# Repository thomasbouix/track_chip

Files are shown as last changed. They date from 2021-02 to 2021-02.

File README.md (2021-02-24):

# TrackChip, le traqueur autonome ! 
L'objectif de ce projet est double :
* Développer un traqueur autonome de précision ~10m (partie Device)
* Récupérer ces informations sur un client WEB (partie Cloud)

### Device
Le device en lui-même est basé sur un micro-controleur ESP32, entouré des périphériques suivant :
* Altimètre BMP180
* GPS ADA746
* Module Sigfox BRKWS01
* Batterie LIPO 1050mAh
* Régulateur de tension 5V Polulu U1V11F5

```
Les sources des bibliothèques des périphériques ainsi que du PCB sont disponibles dans le dossier /devices du git.
```
### Site Web
Le site internet possède les fonctionnalitées suivantes :
* Position de l'utilisateur
* Position du traqueur
* Calcul de la différence d'altitude
* Calcul du trajet en voiture pour rejoindre le traqueur
* Historique des positions du traqueur

```
Les sources du serveur, de la base de donnée et du site Web sont disponibles dans la partie cloud/ du git.
```

# Notice d'utilisation
Le système dans son ensemble possède le comportement suivant :
* Le device utilise le GPS quand il reçoit un signal
* Le device utilise le scrapping WiFi quand le GPS est indisponible
* La position est envoyée sur notre serveur via le réseau SigFox
* Les informations sont accessibles sur notre site via un client Web. 

### Device
Le device s'allume et s'éteint avec le boutton ON/OFF sur le côté de sa boîte protectrice.
Il envoie alors sa position toutes les 5 minutes.
```
Le programme faisant fonctionner le device peut-être modifié et téléversé avec l'IE Arduino.
Il faut simplement s'assurer que les librairies utilisées sont bien visibles en les ajoutant dans ~/Arduino/lib.
```

### Réseau SigFox
Le device envoie ses données sur un backend web en utilisant le réseau SigFox.
Ce backend redirigie ensuite ces informations sur notre serveur grâce à une fonction de callback.
On accède au backend via l'URL suivant :
```
https://backend.sigfox.com/auth/login
```

### Serveur
Le serveur est un ensemble de programmes gérant le site Web ainsi que la base de donnée. 
Il peut être hebergé sur une machine locale, ou bien sur internet via un VPS.
Afin d'avoir accès aux nombreux service de géolocalisation (carte, itinéraire, etc), nous avons utilisé différententes APIs fournies par Google.
Ces APIs nécéssitent une clef pour pouvoir y accéder qu'il faut générer en créant d'abord un compte Google Cloud Platform. 
Puis en copiant-collant cette clef à la place de la notre dans le fichier dev/cloud/php/map.php à la ligne 44 dans le lien du script.
En local, on peut lancer le site avec les commandes suivantes :
```
$ cd /path/to/sources
$ php -S 127.0.0.1.:8888
```

### Site Web
Nous avons choisi d'utiliser l'hébergeur always-data pour notre site.
Cela donnait un URL du type :
```
https://track-chip.alwaysdata.net/
```

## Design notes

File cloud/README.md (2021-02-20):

# Procédure à suivre pour se connecter au site

Ouvrir un navigateur internet (Chrome ou Chromium de préférence, ne fonctionne pas sur Safari) et taper l'adresse suivante : 
```
https://track-chip.alwaysdata.net/cloud/php/map.php
```

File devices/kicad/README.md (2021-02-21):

# KiCad - Architecture

## Librairie
```
Le fichier track_chip.lib contient tout les "symboles" créés pour le projet :
	- ESP32 NodeMCU
	- BMP180
	- ADA746
	- BRKWS01

La librairie contient aussi les symboles déjà présents par défaut dans KiCad, 
afin d'éliminer la dépendance à la version du logiciel.
```

## Schéma
```
Le fichier .sch représente le schéma du circuit électronique du système (Eeschema).
Il instancie les différents symboles de la librairie du projet.
```

## Empreintes

### Dimensions
```
- Largeur typique d'une piste : 1mm
- Largeur typique d'une alimentation : 2mm
- Ecart entre les pastilles : 2.54mm
- Diamètre typique de perçage : 0.8mm
- Diamètre typique de pastille : 1.5mm
```

### Plans de masse
```
Recommendations : faire des plans de masses.
Si il y a un domaine analogique et un domaine numérique, 
faire des plans de masse séparés et les relier avec une piste.
```

## Batterie
```
On utilise un circuit avec chargeur intégré.
```
# Version Sigfox
La version Sigfox utilise un module Wisol pour les communications.
C'est cette version qui a été retenue pour les démonstrations

# Version GSM
La version GSM utilise une carte SIM pour les communications.
Cette version est en cours de développement.

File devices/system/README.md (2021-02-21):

# Classe track_chip
Classe encapsulant les librairies pour les différents périphériques.
(Communication, capteurs, position etc ...)

# Précaution lors de l'upload du code 
Il faut débrancher le broche TX du GPS pour pouvoir téléverser le code depuis l'IDE arduino.
C'est parce que ce gps utilise le même port série que le calbe USB utilisé pour téléverser.

# Architecture du code 
* On utilise la liaison _Serial_ pour imprimer des caractères sur la liaison USB

* Le gps communique avec la liaison _Serial1_ sur les broches RX0 et TX0 de l'ESP32
	+ BAUDE=9600 par défaut

* Le wisol communique avec la liaison _Serial2_ sur les broches RX2 et TX2 de l'ESP32 
	+ BAUDE=9600 par défaut

# examples/class_system/
Ce dossier instancie un code example utilisant la classe track_chip
(En cours de développement)

# examples/bare_system/
Ce dossier instancie un code example utilisant les libairies sans la classe track_chip

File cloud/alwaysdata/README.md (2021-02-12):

# Procedure à suivre pour créer une cles SSH sur le serveur AlwaysData

## Etape 1 :

Générer la clé en local.
		
		$ mkdir -p $HOME/.ssh
		$ chmod 0700 $HOME/.ssh
		$ ssh-keygen -t ed25519 -f $HOME/.ssh/id_ed25519
		
		(tips : vous pouvez indiquez une passphrase vide pour pouvoir vous connecter directement sans la rentrer)

## Etape 2 :

Déclarer la clés publique (.pub) sur le serveur.

		$ ssh-copy-id -i $HOME/.ssh/id_ed25519.pub track-chip@ssh-track-chip.alwaysdata.net

## Etape 3 :

Se connecter au serveur en ssh.

		$ ssh track-chip@ssh-track-chip.alwaysdata.net

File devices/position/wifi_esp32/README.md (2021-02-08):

# Fonctions de localisation grâce aux réseaux Wifi
```
Ces fonctions ont été recopiées et intégrées à la classe TrackChip.
```

# Installation instructions using Arduino IDE Boards Manager
```
- Stable release link: `https://raw.githubusercontent.com/espressif/arduino-esp32/gh-pages/package_esp32_index.json`
- Development release link: `https://raw.githubusercontent.com/espressif/arduino-esp32/gh-pages/package_esp32_dev_index.json`

Starting with 1.6.4, Arduino allows installation of third-party platform packages using Boards Manager. We have packages available for Windows, Mac OS, and Linux (x86, amd64, armhf and arm64).

- Install the current upstream Arduino IDE at the 1.8 level or later. The current version is at the [Arduino website](http://www.arduino.cc/en/main/software).
- Start Arduino and open Preferences window.
- Enter one of the release links above into *Additional Board Manager URLs* field. You can add multiple URLs, separating them with commas.
- Open Boards Manager from Tools > Board menu and install *esp32* platform (and don't forget to select your ESP32 board from Tools > Board menu after installation).
```

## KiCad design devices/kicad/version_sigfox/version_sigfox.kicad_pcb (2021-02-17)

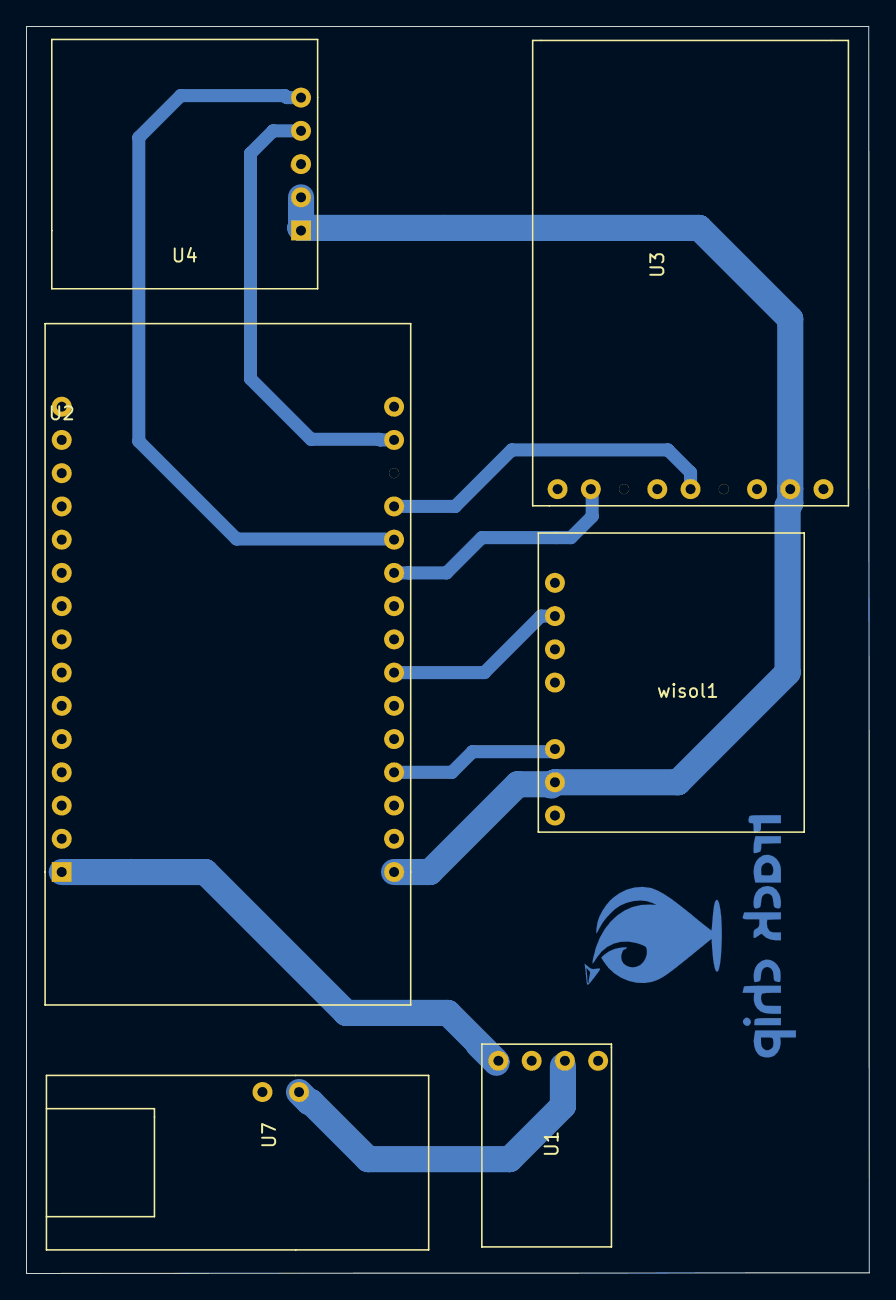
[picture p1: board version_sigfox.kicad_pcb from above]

Board: 2 copper layers, 64.4 x 95.3 mm, 6 parts (0 on the bottom side), 10 nets.

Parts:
U1: polulu
U2: esp32_NodeMCU-track_chip; esp32
U3: GPS_PA6H
U4: bmp180-track_chip; bmp180
U7: charger_mr010
wisol1: brkws01; BRWS01

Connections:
3V3: U2.16, U3.8, U4.1, U4.2, wisol1.6
5V: U1.4, U2.15
EN_GPS: U2.25, U3.2
GND: U1.3, U2.17, U3.7, U4.3, U7.2, wisol1.7
GPS_TX0: U2.27, U3.5
MCU_TX2: U2.22, wisol1.2
RST_WSL: U2.19, wisol1.5
SCL: U2.29, U4.4
SDA: U2.26, U4.5
VBAT: U1.2, U7.1

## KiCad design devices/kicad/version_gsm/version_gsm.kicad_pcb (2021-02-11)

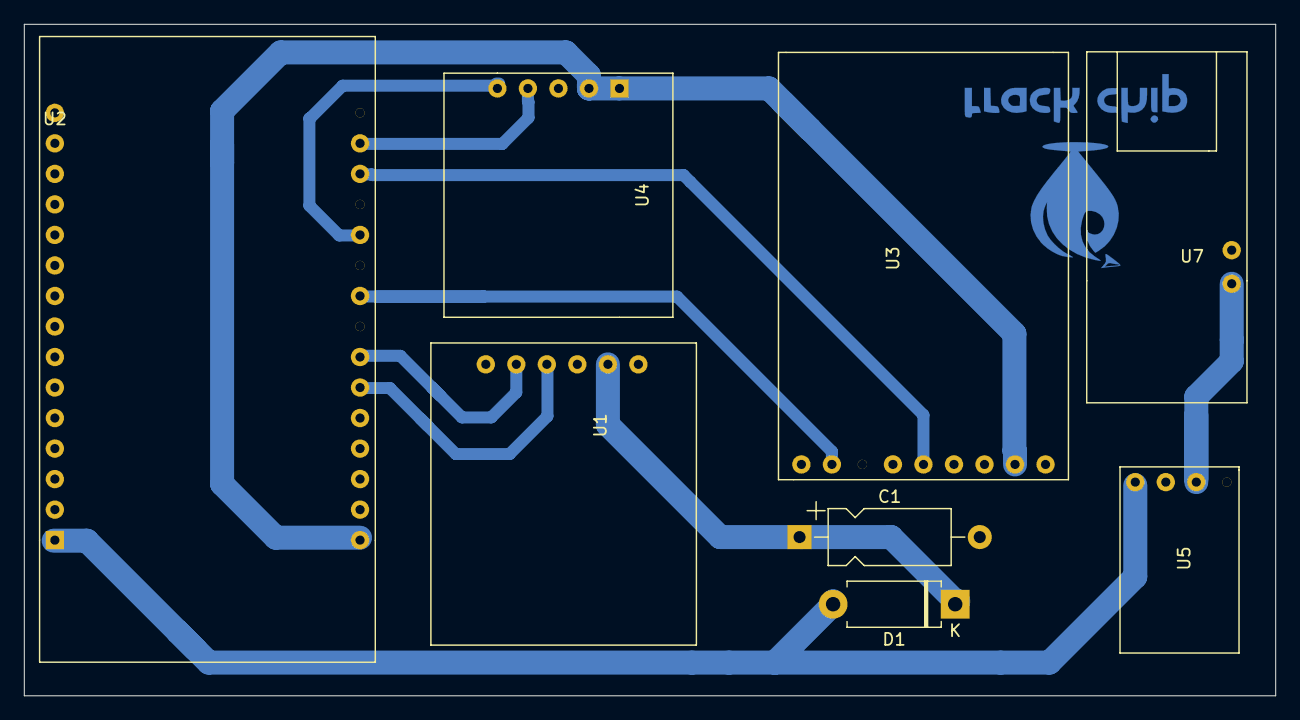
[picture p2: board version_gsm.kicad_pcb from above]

Board: 2 copper layers, 104.1 x 55.9 mm, 8 parts (0 on the bottom side), 11 nets.

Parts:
C1: 100u; CP_Axial_L10.0mm_D4.5mm_P15.00mm_Horizontal
D1: 0.8V; D_DO-15_P10.16mm_Horizontal
U1: SIM800L
U2: esp32_NodeMCU-track_chip; esp32
U3: GPS_PA6H
U4: bmp180-track_chip; bmp180
U5: polulu
U7: charger_mr010

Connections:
3.3V: U2.16, U3.8, U4.1, U4.2
5V: D1.2, U2.15, U5.4
EN_GPS: U2.24, U3.2
GND: C1.2, U1.6, U2.17, U3.7, U4.3, U5.3, U7.2
unnamed: C1.1, D1.1, U1.2
RX2: U1.4, U2.21
SCL: U2.29, U4.4
SDA: U2.26, U4.5
TX0: U2.28, U3.5
TX2: U1.5, U2.22
VBAT: U5.2, U7.1

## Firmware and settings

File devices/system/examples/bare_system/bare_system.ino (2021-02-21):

#include "bare_system.h"

String   mac_address[NB_ADRESSE_MAC];
int      recep_power[NB_ADRESSE_MAC];

uint8_t mac_int[TAILLE_ADRESSE_MAC];

uint8_t bssidtab[NB_ADRESSE_MAC][TAILLE_ADRESSE_MAC];

Wisol w = Wisol();
BMP180I2C bmp = BMP180I2C(BMP_I2C_ADDRESS); 
GROVE11302 gps = GROVE11302();

void setup() {
	Serial.begin(115200); 

	WiFi.mode(WIFI_STA);
	WiFi.disconnect();
	delay(100);
										
	Wire.begin();   
	bmp.init();
}

void loop() {
	chose_message_to_send();
	delay(1000*60*5);
}

void chose_message_to_send() {
	String temp;
	if(receive_fix()) {
		temp = create_message3();
		Wisol::send_string_data(temp);
	} 
	else {
		wifi_scan();

		temp = create_message1();
		temp = Wisol::complete_hexa_bytes(temp, 10);
		Wisol::send_string_data(temp);


		temp = create_message2();
		temp = Wisol::complete_hexa_bytes(temp, 10); 

		delay(1000*30);
		Wisol::send_string_data(temp);
	}
}

void get_bssid(int a) {
	for(int i = 0; i < TAILLE_ADRESSE_MAC ;i++) {
		mac_int[i] = bssidtab[a][i];
	}
}

String create_message1(){
	char temp[2];
	get_bssid(0);
	uint8_t* mac1_addr = mac_int;

	int mac1_power = (-1) * recep_power[0];
	Serial.print("mac1_power : ");
	Serial.println(mac1_power);

	int altitude = (int)(bmp.computeAltitude());
	Serial.print("altitude : ");
	Serial.println(altitude);

	String res = "";

	//AUTH
	String auth = "01";
	res += auth;

	//PUISSANCE
	res+= String(mac1_power, HEX);

	//MAC
	for (int i = 0; i <TAILLE_ADRESSE_MAC;i++){
		sprintf(temp,"%X",mac1_addr[i]);
		String tmp = String(temp);
		res += Wisol::complete_hexa_bytes(tmp, 1);
	}

	// ALTITUDE
	res+= String(altitude, HEX);
	return res;
}

String create_message2(){
	char temp[2];
	get_bssid(1);
	uint8_t* mac2_addr = mac_int;
	int mac2_power = (-1) * recep_power[1];
	int altitude = (int)(bmp.computeAltitude());
	String res = "";

	//AUTH
	String auth = "02";
	res += auth;

	//PUISSANCE
	res+= String(mac2_power, HEX);

	//MAC
	for (int i = 0; i <TAILLE_ADRESSE_MAC;i++){
		sprintf(temp,"%X",mac2_addr[i]);
		String tmp = String(temp);
		res += Wisol::complete_hexa_bytes(tmp, 1);
	}

	//ALTITUDE
	res+= String(altitude, HEX);
	return res;
}

String create_message3(){
	int prec = 5;
	String res; 
	String trame = "$GPGGA,123519,4807.038,N,01131.324,E,1,08,0.9,545.4,M,46.9,M, , *42";//trackChip.get_position();
	int lat_angle, lat_minute; 
	double lat_seconde;
	char lat_c;
	int lng_angle,lng_minute;
	double lng_seconde;
	char lng_c;
	int altitude = bmp.computeAltitude();


	//AUTH
	String auth = "03";
	res += auth;

	//ALTITUDE
	res+=String(altitude, HEX);

	//POSITION
	Wisol::trame_GPGGA_to_DMS(trame, &lat_angle, &lat_minute, &lat_seconde, &lat_c, &lng_angle, &lng_minute, &lng_seconde,  &lng_c);
	res+= Wisol::dms_lat_to_trame_hexa(lat_c, lat_angle, lat_minute, lat_seconde, prec);
	res+= Wisol::dms_lng_to_trame_hexa(lng_c, lng_angle, lng_minute, lng_seconde, prec);

	res = Wisol::complete_hexa_bytes(res, 10);
	return res;
}

void wifi_scan() {    
	int wifi_saved = 0;

	uint8_t *bssid;
	char bssid_str[18];
	int power;

	int n = WiFi.scanNetworks();

	if (n == 0) {
		Serial.println("no networks found");
	}
	else {
		for (int i = 0; i < n; ++i) {
			bssid = WiFi.BSSID(i);
			sprintf(bssid_str, "%X-%X-%X-%X-%X-%X",bssid[5], bssid[4], bssid[3], bssid[2], bssid[1], bssid[0]); 

			power = int(WiFi.RSSI(i));

			// select fix WiFi which are in google database
			if(bssid_str[9] == 'B' && bssid_str[10] == 'D' && wifi_saved < NB_ADRESSE_MAC){
				for(int i = 0; i < TAILLE_ADRESSE_MAC ;i++){
					bssidtab[wifi_saved][i] = bssid[i];
				}

				recep_power[wifi_saved] = power;
				wifi_saved++;
			}
			delay(10);
		}
		// Wait for 1s before scanning again
		delay(1000);
	}
}

bool receive_fix() {
	//GROVE11302 gps_grove = GROVE11302();
	gps.get_data_line();
	char* buf = (char*) gps.buffer;
	String trame = String(buf);
	int MIN_SIZE_CHAR_TRAME = 67;
	return trame.length() >=MIN_SIZE_CHAR_TRAME;
}

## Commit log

2021-01-19 ajout squlette driver bmp180 + scanner i2c
2021-01-21 add README.md for accelerometre_mma8451
2021-01-24 init kicad branch
    [kicad_project.sch]
2021-01-24 update kicad/README
2021-01-26 ajout brkws01
    [kicad_project.sch]
2021-02-01 change device to devices
2021-02-01 ajout GPS ADA746
    + encapsulation de tous les composants dans la librairie du projet
    [kicad_project.sch]
2021-02-01 modification des includes de l'example
2021-02-01 add Arduino WiFi librairy
2021-02-02 system bug fixed => using new() to do dynamic allocation
    [example.ino]
2021-02-04 Test assemblage des fonctions : int_to_hexa bug pour nombre négatif
2021-02-04 refactoring :ajout des fonctions dans la classe sigfox
2021-02-08 adding fingerprints
    [kicad_project.kicad_pcb, kicad_project.sch]
2021-02-08 more fingerprints and symbols
    [kicad_project.kicad_pcb, kicad_project.sch]
2021-02-08 errors fixed
    [kicad_project.sch]
2021-02-09 Refactoring local structure
    [kicad_project.kicad_pcb, kicad_project.sch]
2021-02-09 [PCB] Premier jet
    [kicad_project.kicad_pcb, kicad_project.sch]
2021-02-10 [PCB] version sim en cours
    [kicad_project.kicad_pcb, kicad_project.sch]
2021-02-10 version_sim => version_gsm
    [kicad_project.kicad_pcb, kicad_project.sch]
2021-02-10 Initing sigfox branch
    [kicad_project.kicad_pcb, kicad_project.sch]
2021-02-10 [PCB] Premier jet Sigfox
    [kicad_project.kicad_pcb, kicad_project.sch]
2021-02-10 [PCB] Ajout logo
    [kicad_project.kicad_pcb]
2021-02-10 [PCB] Routage terminé + ajout logo
    [kicad_project.kicad_pcb, kicad_project.sch]
2021-02-10 [PCB] Ajout du plan de coupe
    [kicad_project.kicad_pcb]
2021-02-10 [PCB] Ajout du plan de masse
    [kicad_project.kicad_pcb]
2021-02-10 [PCB] Création des fichiers gerbers
    [kicad_project-B_Cu.gbr, kicad_project-Edge_Cuts.gbr, kicad_project-NPTH.drl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]
2021-02-10 test de la fonction a encapsuler
2021-02-10 [PCB] Premier jet GSM
    [kicad_project.kicad_pcb, kicad_project.sch]
2021-02-11 Fixing sigfox ver
    [kicad_project.kicad_pcb, version_sigfox.kicad_pcb, version_sigfox.sch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]
2021-02-11 fusion récupération, lat, lng à partir de la trame
2021-02-11 test de GPGGA_to_DMS ok
2021-02-11 [PCB] update version gsm
    [kicad_project.kicad_pcb, version_gsm.kicad_pcb, version_gsm.sch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]
2021-02-11 Refactoring : déplacement de l'exemple
2021-02-11 ajout de l'envoie de la trame
2021-02-11 send_trame : conversion et envoie de la trame
2021-02-11 modif de fonction TrackChip::send_data(String s)
2021-02-14 demonstration+ affichage des fonctions de conversion
2021-02-15 fixing sigfox pcb
    [version_sigfox.kicad_pcb, version_sigfox.sch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]
2021-02-16 correction symbole + empreinte sigfox
    [version_sigfox.kicad_pcb, version_sigfox.sch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]
2021-02-16 numérotation du wisol dans le eeschema
    [version_sigfox.sch]
2021-02-16 changement de structure
2021-02-17 sauvegarde des bssid BD : optimal pour la démo
2021-02-17 ajout de la puissance dans les messages
